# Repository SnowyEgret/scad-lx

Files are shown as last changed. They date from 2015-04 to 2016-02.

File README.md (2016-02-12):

# scad-lx

### woofer_adapter.scad
Connects the rubber coupler to the woofer and fullrange diffuser. Has holes for #6 machine screw mount of driver with a gasket. Wire hole must be sealed. Dimesions are derived in part from dimensions of rubber coupler defined in plumbing.scad.

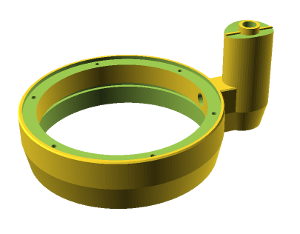
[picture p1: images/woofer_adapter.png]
woofer_adapter


### base.scad
Connects to the bottom of the woofer pipe and has 3 or more legs with holes for insetings threaded inserts for adjustable feet. Has an opening underneath for accessing the interior of the pipe and is closed by a terminal cups. Unless your printer has an enormous bed, the ring and legs will have to be printed separately. Should be printed upside down.

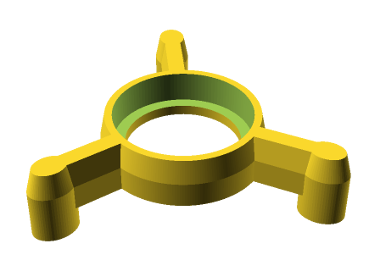
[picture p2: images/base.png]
base


### fullrange_adapter.scad
Mounts the fullrange driver to the diffuser. Openings behind the driver allow sound to propagate to the rear.

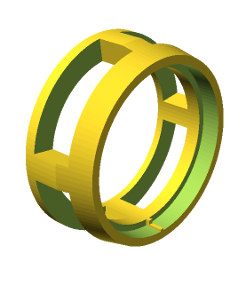
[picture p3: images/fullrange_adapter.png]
fullrange_adapter


### fullrange_cap.scad
Caps the rear end of the diffuser.

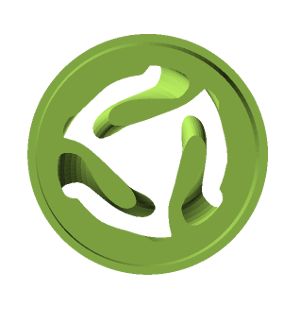
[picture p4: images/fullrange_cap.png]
fullrange_cap


### terminal_cup.scad
Closes the bottom of the base and has recesses and mounts for banana plugs. If a SpeakON connector is mounted on the woofer pipe, then the banana plugs are not necessary and the cup should be printed flat.

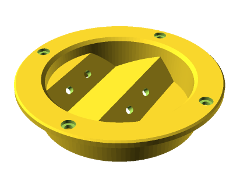
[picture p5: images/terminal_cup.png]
terminal_cup


### woofer_cover.scad
A cover which fits over the woofer adapter and protects the woofer from damage. Not intended to be used operationaly. Has a configurable logo. Should be printed upside down. (I have never printed one of these)

### cradle.scad
Deprecated. The woofer adapter mounts directly to the diffuser now.

### lx.scad
Critical dimensions of SL design and drivers.

### plumbing.scad
ABS pipe and the rubber connector.

### elbow.scad
An elbow with cylindrical extensions. Used by woofer_adapter to created the hole for the fullrange driver wires.

### util.scad
Generic utility modules. Used directly or indirectly by most high level assemblies.

## Notes
These models are all parametric. Pretty well anything is configurable including the number of legs on the base. The ABS pipe and rubber coupler should be purchased and measured amd their dimensions set before printing. I started my prints and aborted them after a few layers to make sure there was a tight fit to the ABS pipes. Parameters are defined at the top of each file, after the includes. Modules follow, and are ordered from highest assembly to lowest. The call to the top level module might need uncommenting if the file is drawing nothing (immediatly after includes). If the file is included, you might want to comment out these calls to prevent it from being drawn. There are no .stl files provided. OpenSCAD exports stl for printing.

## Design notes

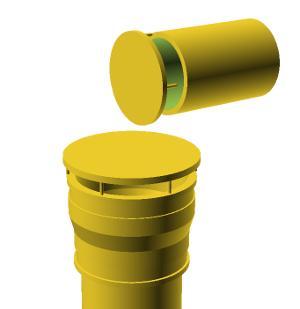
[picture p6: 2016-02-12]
images/lx.png

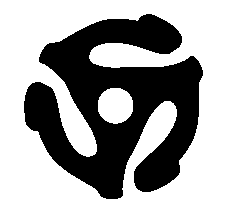
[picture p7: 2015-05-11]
images/45insert.png

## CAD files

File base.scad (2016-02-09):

include <util.scad>;
include <lx.scad>;
include <woofer_adapter.scad>;
include <terminal_cup.scad>;

$fn=120;
base();
//base_less_terminal_cup();
//base_less_woofer_pipe();
//base_assembled();
//base_ring();
//base_leg();
//woofer_post_drilled();
//threaded_insert();

num_legs=3;

//The top and bottom rings are the same profile
base_ring_height=woofer_ring_height;
base_ring_inner_radius=cup_shaft_outer_radius;
base_ring_width=20;
base_ring_pipe_inset=base_ring_height-15;
base_ring_pipe_inner_radius_tolerance=.9;
base_ring_pipe_inner_radius=woofer_pipe_outer_radius + base_ring_pipe_inner_radius_tolerance;

base_leg_height=base_ring_height+20;
base_leg_inset=5;
base_leg_length=60;

threaded_insert_head_radius=6.1;
threaded_insert_head_length=1.5;
threaded_insert_shaft_radius=4.5;
threaded_insert_length=20;

print_bed_width=200;

module base() {
  //%print_bed();
  base_legs();
  base_less_terminal_cup();
}

module base_less_terminal_cup() {
  difference() {
    base_less_woofer_pipe();
    rotate([0,0,45])
      scale([1,1,-1])
        translate([0,0,base_ring_height])
          union() {
            terminal_cup(screw_holes=true, radius_tolerance=.5, $fn=120);
            terminal_cup_gasket($fn=120);
          }
  }
}

module base_less_woofer_pipe() {
    difference() {
      base_assembled();
      translate([0,0,-base_ring_pipe_inset])
        cylinder(r=base_ring_pipe_inner_radius, h=100, $fn=120);
    }
}

module base_assembled() {
  difference() {
    base_ring();
    base_legs();
  }
}

module base_legs() {
  radial_array(n=num_legs) {
    base_leg();
  }
}

module base_ring() {
  scale([1,1,-1]) 
    woofer_ring(inner_radius=base_ring_inner_radius, width=base_ring_width);
}

module base_leg() {
  scale([1,1,-1]) 
    translate([woofer_pipe_outer_radius+base_leg_inset,0,0]) {
      translate([base_leg_length, 0,0])
        woofer_post_drilled();
    woofer_connector(length=base_leg_length);
  }
}

module woofer_post_drilled() {
  difference() {
   woofer_post(height=base_leg_height);
    translate([0,0,base_leg_height+.001])
      mirror([0,0,1])
        threaded_insert();
  }
}

module threaded_insert() {
   cylinder(r=threaded_insert_shaft_radius, h=threaded_insert_length);
   cylinder(r=threaded_insert_head_radius, h=threaded_insert_head_length);
}

module print_bed() {
  translate([0,0,-base_leg_height])
  cube(size=[print_bed_width,print_bed_width,1], center=true);
}

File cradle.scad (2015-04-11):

include <lx.scad>;
//include <woofer_adapter.scad>;
include <util.scad>;

//cradle($fn=180);

// The distance the cradle extends past the long dimension of the oval post
cradle_length_offset=6;
//cradle_length=2*woofer_post_long_radius+cradle_length_offset*2;
cradle_length=50;
cradle_inner_radius=fullrange_pipe_outer_radius;
cradle_thickness=4;
cradle_outer_radius=cradle_inner_radius+cradle_thickness;
cradle_angle=55;

cradle_screw_angle_inset=16;
cradle_screw_angle=cradle_angle-cradle_screw_angle_inset;
cradle_screw_inset=8;
cradle_screw_offset=cradle_length/2-cradle_screw_inset;
// Number 6 machine srew
cradle_screw_hole_shaft_radius=3.6/2;
cradle_screw_hole_head_radius=6.8/2;

cradle_key_width=2.2;
cradle_key_depth=2;
// The key is inset from the woofer post
cradle_key_inset=cradle_length_offset+3;

//cradle_peg_radius=woofer_ring_wire_hole_radius+3;
cradle_peg_radius=3/8*m-.1;
cradle_peg_height=fullrange_pipe_thickness+3;

module cradle() {
  translate([0,0,cradle_inner_radius])
  rotate([0,90.0])
  difference() {
    union() {
      difference() {
        radial_section_of(angle=cradle_angle) {
          hollow_cylinder(ir=cradle_inner_radius, t=cradle_thickness, h=cradle_length);
        }
        screw_holes();
      }
      key();
      peg();
    }
    cradle_wire_hole();
  }
}

module cradle_wire_hole() {
  rotate([0,90,0])
    cylinder(r=6, h=100);
}

module peg() {
  translate([cradle_inner_radius+cradle_thickness/2,0,0])
    rotate([0,-90,0])
      cylinder(r=cradle_peg_radius, h=cradle_peg_height+cradle_thickness/2);
}

module key() {
  translate([cradle_inner_radius+cradle_thickness/2,0,0])
    cube(size=[
      2*cradle_key_depth+cradle_thickness,
      cradle_key_width,
      cradle_length-2*cradle_key_inset
    ], center=true);
}

module screw_holes() {
  for(d=[-cradle_screw_offset, cradle_screw_offset]) {
    translate([0,0,d])
      for(a=[-cradle_screw_angle, cradle_screw_angle]) {
        rotate([0,0,a/2])
          translate([cradle_inner_radius+cradle_thickness/2.2,0,0])
            rotate([0,90,0])
              screw_hole(r_shaft=cradle_screw_hole_shaft_radius, r_head=cradle_screw_hole_head_radius);
      }
  }
}

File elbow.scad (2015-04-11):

//http://forum.openscad.org/hull-to-create-elbow-not-working-td11667.html
//elbow(lv=10, lh=20);

module elbow(bend_radius=5, pipe_radius=1.5, lv=10, lh=10, detail=30) {
  translate([0,0,bend_radius+pipe_radius])
    cylinder(r=pipe_radius, lv, $fn=detail);  
  translate([0,-bend_radius,pipe_radius])
    rotate([90,0,0])
      cylinder(r=pipe_radius, lh, $fn=detail);
  bend(r=bend_radius, rc=pipe_radius, detail=detail);
}

module bend(r, rc, detail){
  translate([0,0,r+rc])
    rotate([0,90,0])
      translate([0,-r,0])
        difference(){
          rotate_extrude($fn=60,convexity=4)
            translate([r,0])
              rotate([0,0,360/detail/2])
                circle(rc,$fn=detail);
            translate([0,-2*r,0])
              cube(4*r,true);
            translate([-2*r,0,0])
              cube(4*r,true);
        }
}

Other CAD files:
images/45insert.dxf
fullrange_adapter.scad
fullrange_cap.scad
lx.scad
plumbing.scad
terminal_cup.scad
util.scad
woofer_adapter.scad
woofer_cover.scad

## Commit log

2015-04-11 Initial version
    [base.scad, cradle.scad, elbow.scad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]
2015-04-14 Last chnages before final print
    [fullrange_adapter.scad, fullrange_cap.scad, lx.scad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]
2015-05-11 Modified fullrange cap
    [45insert.dxf, fullrange_cap.scad, util.scad]
2016-02-09 Improved Readme
    [base.scad, lx.scad, woofer_adapter.scad]
2016-02-11 Comments for OPLUG"
    [lx.scad, woofer_adapter.scad]
2016-02-12 Comments for OPLUG
    [lx.scad, plumbing.scad]
2016-02-12 Images for readme
    [lx.scad, terminal_cup.scad, woofer_adapter.scad]
